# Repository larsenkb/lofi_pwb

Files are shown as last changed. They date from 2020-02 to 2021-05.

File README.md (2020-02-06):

# lofi window/door sensor

## Uses attiny84a + nrf24l01p + tpl5111 to achieve very low power.

This project was influenced by a LoFi board designed by
David Cook and entered in a hackaday contest.
See https://hackaday.io/project/1552-lofi

At the beginning, I used OshPark to make some of his
boards and hacked them to work with an NRF24l01+.

I have mated the lofi board with a nrf24l01+ instead of using
the 433 MHz transmitter described at the above link.

I'm using the nrf24 in its very basic form, using minimal
features.

I am using parts of xprintf.[ch] by ChaN (see xprintf.c for copyright)
I am using parts of nrf24.[ch] by <ihsan@ehribar.me>
(see nrf24.c for license)

The lofi+nrf24 combo draws ~2 uA in the idle mode.
It can monitor one reed switch, Vcc and internal temperature.
It uses the internal RC oscillator so timing is not very accurate.
The switch can be configured to generate an interrupt on Pin Change
which will trigger a transmission. Otherwise, it is only polled
and switch state will be transmitted at the polling frequency.
The polling period is configured in eeprom, to be a multiple
of the TPL5111 period.

The LDO can be installed if you want to power lofi from a voltage > 3.3V. Otherwise, just solder a jumper across the Vin to Vout of the LDO.

Resistors R1, R2, and R3 are in parallel-series so you can get a precise timing resistance with less precise resistors.

I use a SPDT reed switch so that I do not need a pull-up or pull-down resistor, thus reducing power further.

A 10-bit incrementing count can also be enabled and will be
sent at a frequency determined by eeprom and TPL5111.

I am making my own board now that uses a TPL5111 to periodically
wake the ATtiny84. I do not power down the t84 but instead,
use a Pin Change function to monitor the TPL5111 DRVn pin.
So, I continuously draw about 2uA.
I chose this method, so that my original code did not have
to change much. I can still use SRAM between sleeps.
If I powered down the t84 between DRVn assertions, I would
have to send all messages each time. I don't think there
would be a method of only sending Vcc messages every n
DRV assertions.

I'm using spin loop delays. See util/delay basic.h.  delay_loop_1 loop is three cycles and takes an 8-bit loop counter. 3us * 256 is max delay.  delay_loop_2 loop is four cycles and takes a 16-bit loop counter. 4us * 65536 is max delay.

Configuration is stored in the eeprom starting at addr 0.
See config_t structure for details.

---

The front view of lofi looks like this:
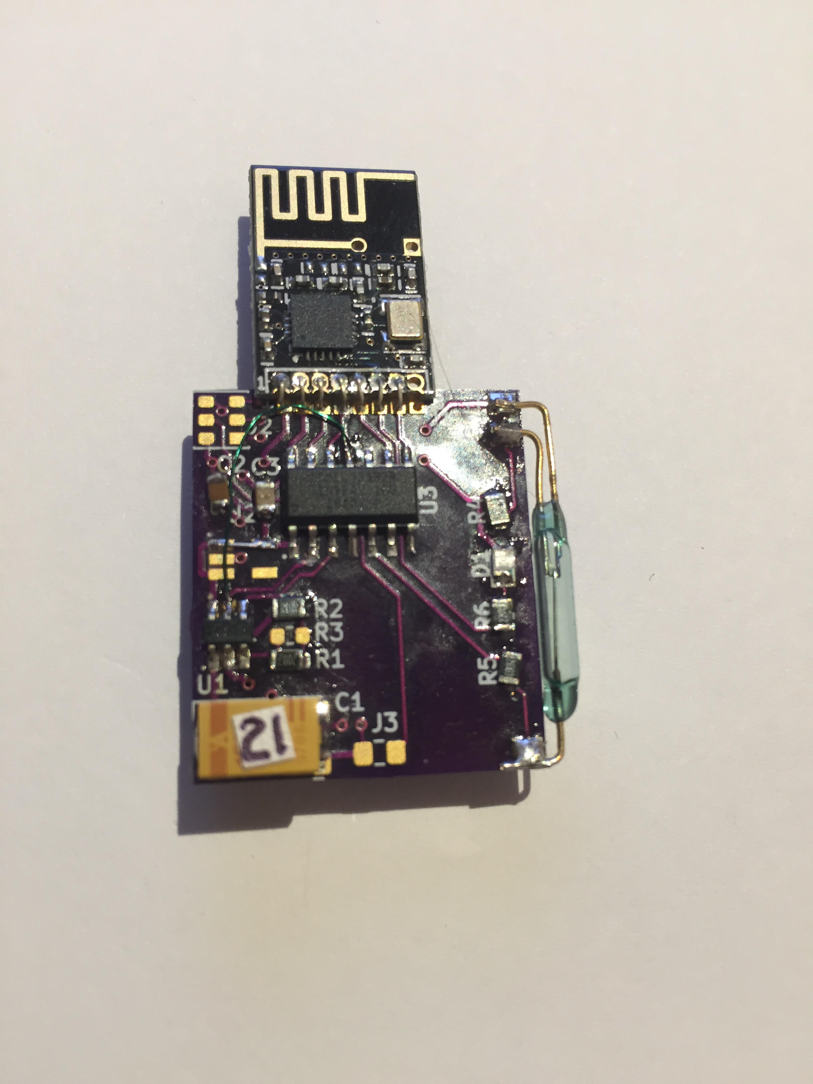
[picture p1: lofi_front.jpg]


The back view of lofi looks like this:
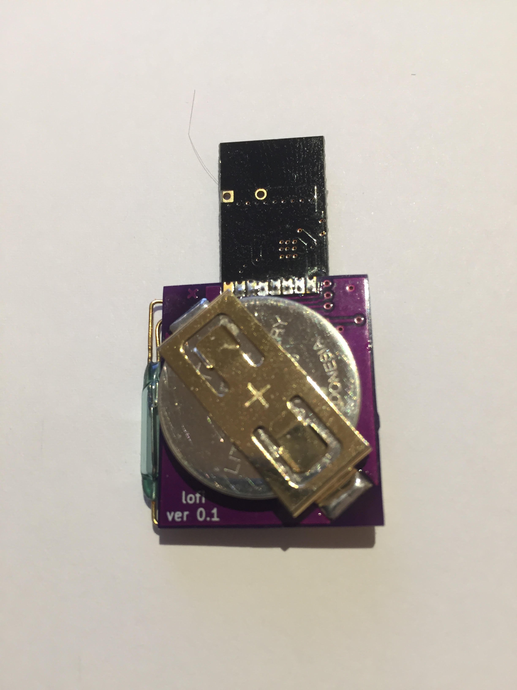
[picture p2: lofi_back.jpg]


The folded view of lofi looks like this:
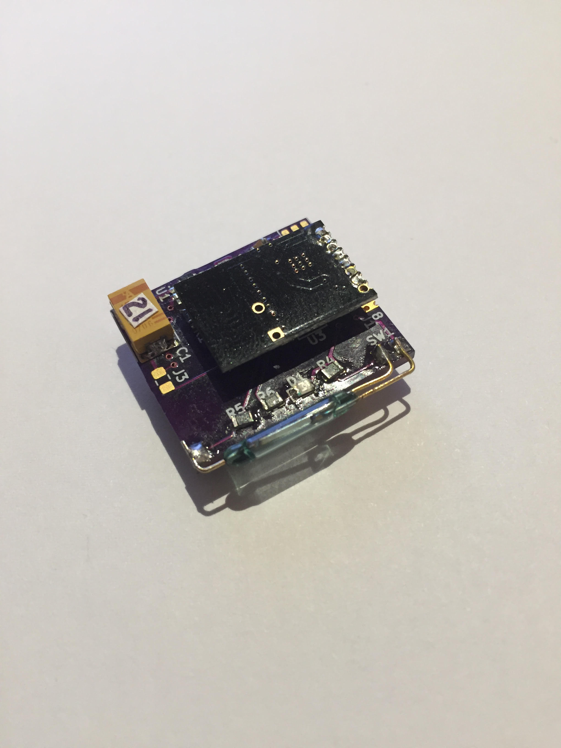
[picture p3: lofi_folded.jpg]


I used a clothes pin to make my programmer:
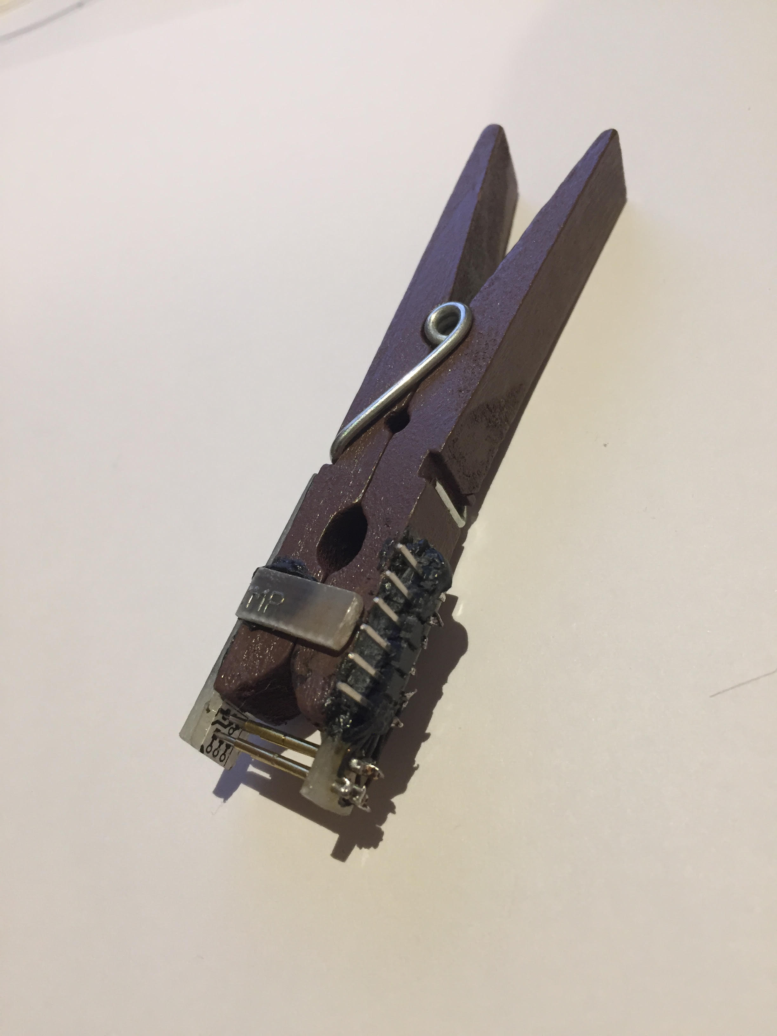
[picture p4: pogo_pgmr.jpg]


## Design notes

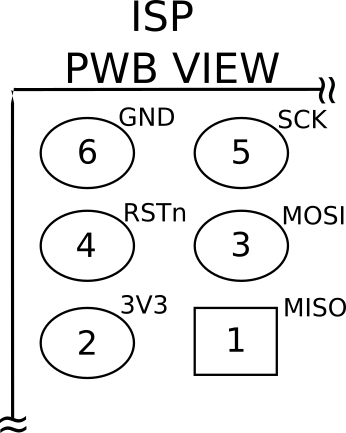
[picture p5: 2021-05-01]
isp_pwb.svg-path10-603.png

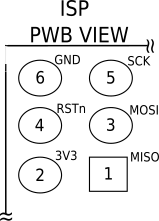
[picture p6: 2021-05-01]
isp_pwb.png

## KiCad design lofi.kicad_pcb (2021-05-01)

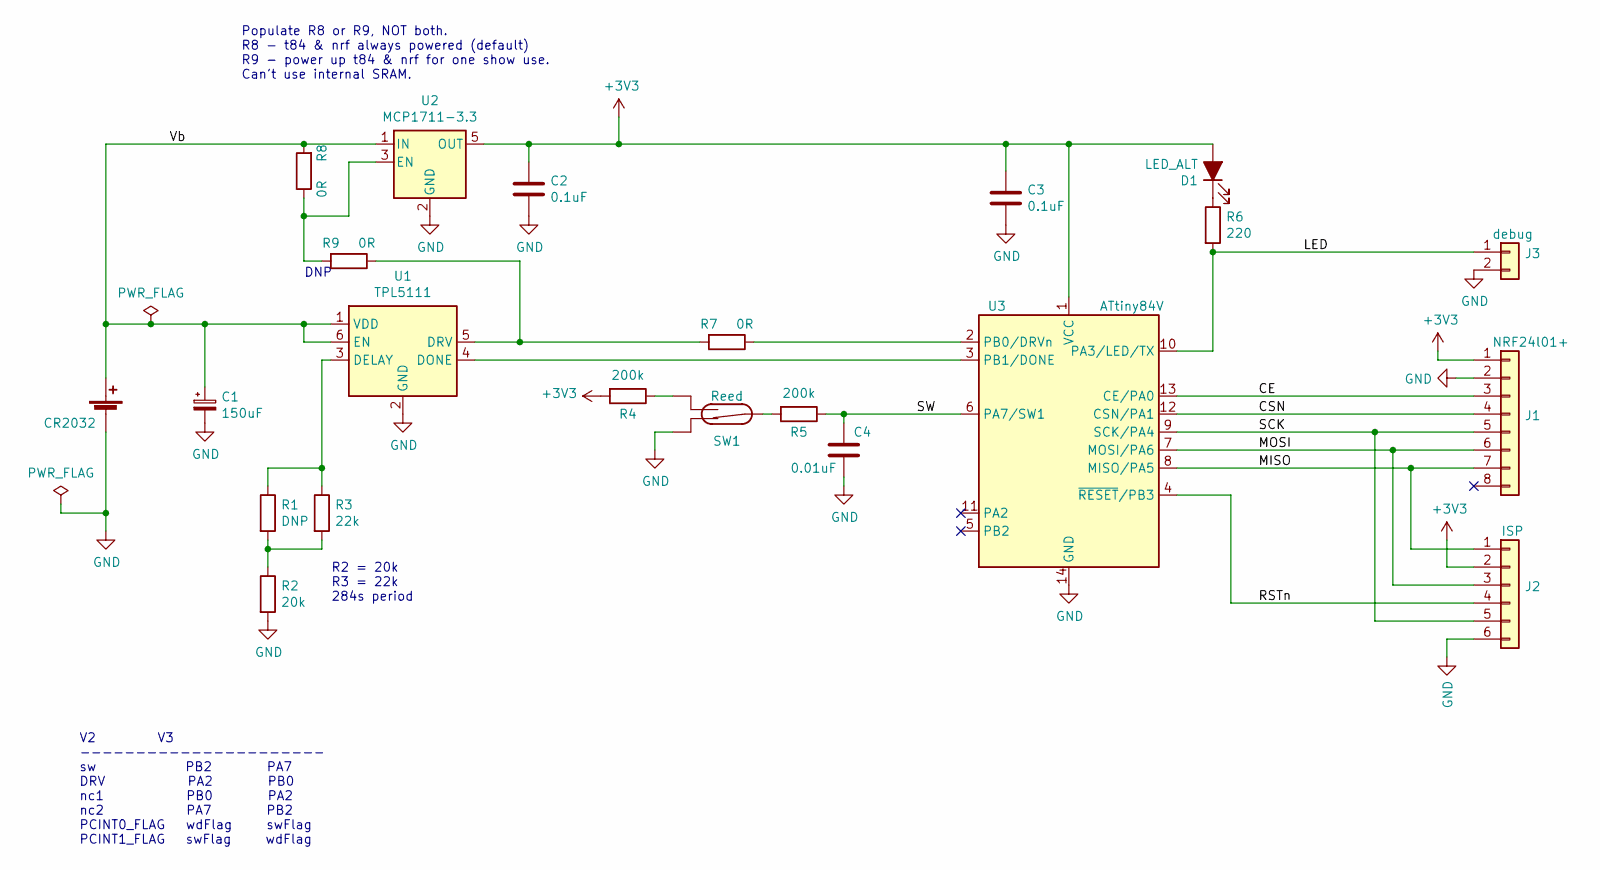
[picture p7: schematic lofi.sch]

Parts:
BT1: CR2032; CR2032_battery_clip
C1: 150uF; C_2816_7142Metric_Pad3.20x4.45mm_HandSolder
C2, C3: 0.1uF; C_0805_2012Metric_Pad1.15x1.40mm_HandSolder
C4: 0.01uF; C_0805_2012Metric_Pad1.15x1.40mm_HandSolder
D1: LED_ALT; D_0805_2012Metric_Pad1.15x1.40mm_HandSolder
J1: NRF24l01+; nrf24l01p
J2: ISP
J3: debug; R_0805_2012Metric_Pad1.15x1.40mm_HandSolder
R1: DNP; R_0805_2012Metric_Pad1.15x1.40mm_HandSolder
R2: 20k; R_0805_2012Metric_Pad1.15x1.40mm_HandSolder
R3: 22k; R_0805_2012Metric_Pad1.15x1.40mm_HandSolder
R4, R5: 200k; R_0805_2012Metric_Pad1.15x1.40mm_HandSolder
R6: 220; R_0805_2012Metric_Pad1.15x1.40mm_HandSolder
R7: 0R; R_0805_2012Metric_Pad1.15x1.40mm_HandSolder
R8, R9: 0R; R_0805_2012Metric_Pad1.20x1.40mm_HandSolder
SW1: Reed; REED_SPDT
U1: TPL5111
U2: MCP1711-3.3; MCP1711
U3: ATtiny84V; SOIC-14

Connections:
+3V3: C2.1, C3.1, D1.2 (A), J1.1, J2.2, R4.2, U2.5 (OUT), U3.1 (VCC)
/CE: J1.3, U3.13 (CE/PA0)
/CSN: J1.4, U3.12 (CSN/PA1)
/LED: J3.1, R6.2, U3.10 (PA3/LED/TX)
/MISO: J1.7, J2.1, U3.8 (MISO/PA5)
/MOSI: J1.6, J2.3, U3.7 (MOSI/PA6)
/RSTn: J2.4, U3.4 (~RESET~/PB3)
/SCK: J1.5, J2.5, U3.9 (SCK/PA4)
/SW: C4.1, R5.1, U3.6 (PA7/SW1)
/Vb: BT1.1 (+), C1.1, R8.2, U1.1 (VDD), U1.6 (EN), U2.1 (IN)
GND: BT1.2 (-), C1.2, C2.2, C3.2, C4.2, J1.2, J2.6, J3.2, R2.2, SW1.1, U1.2 (GND), U2.2 (GND), U3.14 (GND)
unnamed: D1.1 (K), R6.1
unnamed: R1.1, R3.1, U1.3 (DELAY)
unnamed: R1.2, R2.1, R3.2
unnamed: R4.1, SW1.3
unnamed: R5.2, SW1.2
unnamed: R7.1, U3.2 (PB0/DRVn)
unnamed: R7.2, R9.1, U1.5 (DRV)
unnamed: R8.1, R9.2, U2.3 (EN)
unnamed: U1.4 (DONE), U3.3 (PB1/DONE)

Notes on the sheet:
DNP
Populate R8 or R9, NOT both. R8 - t84 & nrf always powered (default) R9 - power up t84 & nrf for one show use. Can't use internal SRAM.
V2 V3 ---------------------- sw PB2 PA7 DRV PA2 PB0 nc1 PB0 PA2 nc2 PA7 PB2 PCINT0_FLAG wdFlag swFlag PCINT1_FLAG swFlag wdFlag
R2 = 20k R3 = 22k 284s period

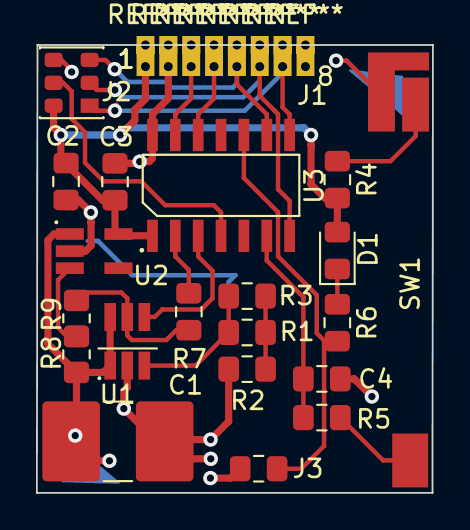
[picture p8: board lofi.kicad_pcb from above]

Board: 2 copper layers, 22.0 x 24.9 mm, 22 parts (1 on the bottom side), 20 nets.

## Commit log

2019-08-16 initial checkin
    [lofi-B_Cu.gbr, lofi-B_Mask.gbr, lofi-B_Paste.gbr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]
2019-08-16 changed SOIC-14 footprint
    [lofi.kicad_pcb]
2019-08-17 as sent to OSHPark
    [lofi-B_Cu.gbr, lofi-B_Mask.gbr, lofi-B_Paste.gbr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]
2019-08-17 really, this time, as sent to OSHPark
    [lofi-NPTH.drl, lofi-PTH.drl]
2020-02-06 version 0.2 and 0.3
    [lofi.kicad_pcb, lofi.sch]
2021-05-01 latest pwb version is 0.4
    [lofi-B_Cu.gbr, lofi-B_Mask.gbr, lofi-B_Paste.gbr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]
